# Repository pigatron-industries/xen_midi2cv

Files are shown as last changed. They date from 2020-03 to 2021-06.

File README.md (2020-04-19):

# MIDI - CV

MIDI to control voltage converter.

Uses [PJRC Teensy 4.0](https://www.pjrc.com/teensy-4-0/) and [MikroElektronika PIXI Click](https://www.mikroe.com/pixi-click) for IO.

## Hardware

Hardware functions are split into various PCBs.

* PGTNX05 Mainboard - Contains the Teensy 4 CPU, 2x MIDI Inputs and Outputs, 1x PIXI Click for 20 CV Outputs (12-bit).
* PGTNX06 IO Expander - Space for another 2x PIXI Click boards for up to 40 CV inputs or outputs.
* PGTNX07 Gate Output - 32x Gate/Trigger outputs.
* PGTNX08 Pitch Output - 8x 16-bit CV outputs for 1v/oct pitch control.

## Features

* 8 output channels each giving a Gate, Trigger, Pitch, Velocity and 2 Control Change outputs.
* Can be configured for a single MIDI channel to be mapped to multiple output channels for polyphonic operation.
* 8 separate percussion channel outputs with Trigger, and 2 Control Change outputs each, which can be mapped to individual notes on a single MIDI channel.

## Compiling

### Protobuf

Protobuf is used as a lightweight way of sending configuration data over midi sysex messages. The format of the message is specified in protobuf/ConfigMessage.proto.

If any changes are made to the format, the .c and .h files in the protobuf folder will need to be regenerated using the protobuf compiler.

This can be installed on Mac using the following commands:

`brew install protobuf`

`brew install nanopb-generator`

Then running the build.sh script will do the compilation.

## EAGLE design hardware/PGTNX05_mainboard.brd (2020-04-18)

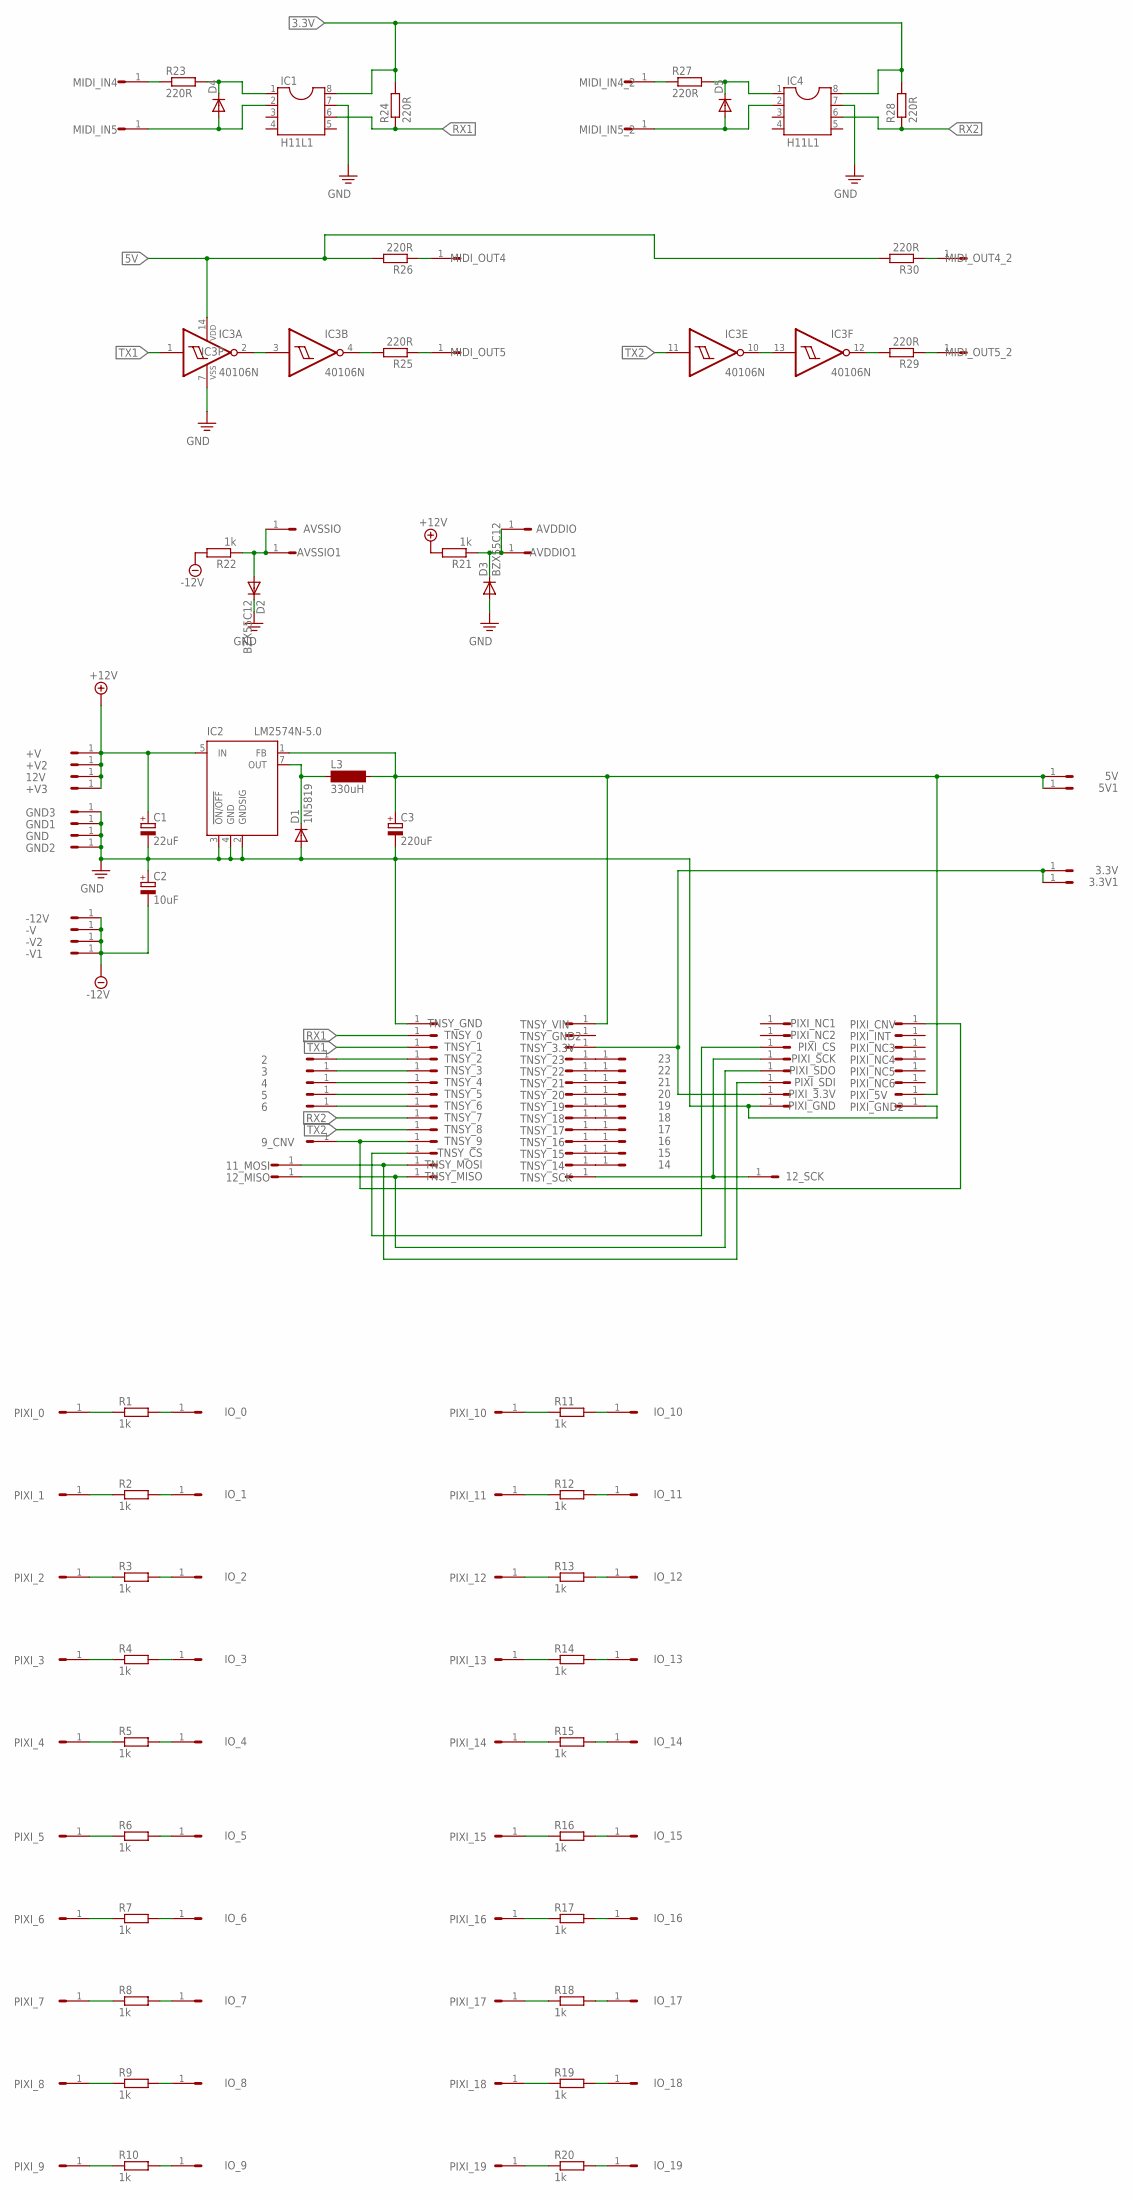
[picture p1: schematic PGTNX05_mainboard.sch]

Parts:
2, 3, 3.3V, 3.3V1, 4, 5, 5V, 5V1, 6, 9_CNV, 11_MOSI, 12V, 12_MISO, 12_SCK, 14, 15, 16, 17, 18, 19, 20, 21, 22, 23: HEADER/MALE/01
+V, +V2, +V3: HEADER/MALE/01
-12V: HEADER/MALE/01
-V, -V1, -V2: HEADER/MALE/01
AVDDIO, AVDDIO1: HEADER/MALE/01
AVSSIO, AVSSIO1: HEADER/MALE/01
C1: 22uF; E5-10,5
C2: 10uF; E2,5-6
C3: 220uF; E2,5-6
D1: 1N5819; DO35-7
D2, D3: BZX55C12; DO35-7
D4, D5: 1N4148DO35-7; DO35-7
GND, GND1, GND2, GND3: HEADER/MALE/01
IC1, IC4: H11L1; DIL08
IC2: LM2574N-5.0; DIL08
IC3: 40106N; DIL14
IO_0, IO_1, IO_2, IO_3, IO_4, IO_5, IO_6, IO_7, IO_8, IO_9, IO_10, IO_11, IO_12, IO_13, IO_14, IO_15, IO_16, IO_17, IO_18, IO_19: HEADER/MALE/01
L3: 330uH; BS11
MIDI_IN4, MIDI_IN4_2, MIDI_IN5, MIDI_IN5_2: HEADER/MALE/01
MIDI_OUT4, MIDI_OUT4_2, MIDI_OUT5, MIDI_OUT5_2: HEADER/MALE/01
PIXI_0, PIXI_1, PIXI_2, PIXI_3, PIXI_3.3V, PIXI_4, PIXI_5, PIXI_5V, PIXI_6, PIXI_7, PIXI_8, PIXI_9, PIXI_10, PIXI_11, PIXI_12, PIXI_13, PIXI_14, PIXI_15, PIXI_16, PIXI_17, PIXI_18, PIXI_19: HEADER/MALE/01
PIXI_CNV: HEADER/MALE/01
PIXI_CS: HEADER/MALE/01
PIXI_GND, PIXI_GND2: HEADER/MALE/01
PIXI_INT: HEADER/MALE/01
PIXI_NC1, PIXI_NC2, PIXI_NC3, PIXI_NC4, PIXI_NC5, PIXI_NC6: HEADER/MALE/01
PIXI_SCK: HEADER/MALE/01
PIXI_SDI: HEADER/MALE/01
PIXI_SDO: HEADER/MALE/01
R1, R2, R3, R4, R5, R6, R7, R8, R9, R10, R11, R12, R13, R14, R15, R16, R17, R18, R19, R20, R21, R22: 1k; RESISTOR/7.5
R23, R24, R25, R26, R27, R28, R29, R30: 220R; RESISTOR/7.5
TNSY_0, TNSY_1, TNSY_2, TNSY_3, TNSY_3.3V, TNSY_4, TNSY_5, TNSY_6, TNSY_7, TNSY_8, TNSY_9, TNSY_14, TNSY_15, TNSY_16, TNSY_17, TNSY_18, TNSY_19, TNSY_20, TNSY_21, TNSY_22, TNSY_23: HEADER/MALE/01
TNSY_CS: HEADER/MALE/01
TNSY_GND, TNSY_GND2: HEADER/MALE/01
TNSY_MISO: HEADER/MALE/01
TNSY_MOSI: HEADER/MALE/01
TNSY_SCK: HEADER/MALE/01
TNSY_VIN: HEADER/MALE/01

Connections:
3.3V: 3.3V.1, 3.3V1.1, IC1.8, IC4.8, PIXI_3.3V.1, R24.2, R28.2, TNSY_3.3V.1
5V: 5V.1, 5V1.1, C3.+, IC2.1 (FB), IC3.14 (VDD), L3.2, PIXI_5V.1, R26.2, R30.2, TNSY_VIN.1
+12V: 12V.1, +V.1, +V2.1, +V3.1, C1.+, IC2.5 (IN), R21.2
-12V: -12V.1, -V.1, -V1.1, -V2.1, C2.-, R22.2
GND: C1.-, C2.+, C3.-, D1.A, D2.C, D3.A, GND.1, GND1.1, GND2.1, GND3.1, IC1.7, IC2.2 (GNDSIG), IC2.3 (!ON/OFF), IC2.4 (GND), IC3.7 (VSS), IC4.7, PIXI_GND.1, PIXI_GND2.1, TNSY_GND.1
unnamed: 17.1, TNSY_17.1
unnamed: 16.1, TNSY_16.1
unnamed: D1.C, IC2.7 (OUT), L3.1
unnamed: 12_MISO.1, PIXI_SDO.1, TNSY_MISO.1
unnamed: PIXI_CS.1, TNSY_CS.1
unnamed: 18.1, TNSY_18.1
unnamed: 19.1, TNSY_19.1
unnamed: 20.1, TNSY_20.1
unnamed: 21.1, TNSY_21.1
unnamed: 22.1, TNSY_22.1
unnamed: 23.1, TNSY_23.1
unnamed: 15.1, TNSY_15.1
unnamed: 2.1, TNSY_2.1
unnamed: 3.1, TNSY_3.1
unnamed: 4.1, TNSY_4.1
unnamed: 5.1, TNSY_5.1
unnamed: PIXI_0.1, R1.1
unnamed: IO_0.1, R1.2
unnamed: PIXI_1.1, R2.1
unnamed: 6.1, TNSY_6.1
unnamed: IO_1.1, R2.2
unnamed: 9_CNV.1, PIXI_CNV.1, TNSY_9.1
unnamed: 11_MOSI.1, PIXI_SDI.1, TNSY_MOSI.1
unnamed: PIXI_2.1, R3.1
unnamed: 12_SCK.1, PIXI_SCK.1, TNSY_SCK.1
unnamed: 14.1, TNSY_14.1
unnamed: IO_2.1, R3.2
unnamed: PIXI_3.1, R4.1
unnamed: IO_3.1, R4.2
unnamed: PIXI_4.1, R5.1
unnamed: IO_4.1, R5.2
unnamed: PIXI_5.1, R6.1
unnamed: IO_5.1, R6.2
unnamed: PIXI_6.1, R7.1
unnamed: IO_6.1, R7.2
unnamed: PIXI_7.1, R8.1
unnamed: IO_7.1, R8.2
unnamed: PIXI_8.1, R9.1
unnamed: IO_8.1, R9.2
unnamed: PIXI_9.1, R10.1
unnamed: IO_9.1, R10.2
unnamed: PIXI_10.1, R11.1
unnamed: IO_10.1, R11.2
unnamed: PIXI_11.1, R12.1
unnamed: IO_11.1, R12.2
unnamed: PIXI_12.1, R13.1
unnamed: IO_12.1, R13.2
unnamed: PIXI_13.1, R14.1
unnamed: IO_13.1, R14.2
unnamed: PIXI_14.1, R15.1
unnamed: IO_14.1, R15.2
unnamed: PIXI_15.1, R16.1
unnamed: IO_15.1, R16.2
unnamed: PIXI_16.1, R17.1
unnamed: IO_16.1, R17.2
unnamed: PIXI_17.1, R18.1
unnamed: IO_17.1, R18.2
unnamed: PIXI_18.1, R19.1
unnamed: IO_18.1, R19.2
unnamed: AVDDIO.1, AVDDIO1.1, D3.C, R21.1
unnamed: AVSSIO.1, AVSSIO1.1, D2.A, R22.1
unnamed: PIXI_19.1, R20.1
unnamed: IO_19.1, R20.2
unnamed: MIDI_IN4.1, R23.1
unnamed: D4.C, IC1.1, R23.2
unnamed: D4.A, IC1.2, MIDI_IN5.1
unnamed: IC3.2 (O), IC3.3 (I)
unnamed: IC3.4 (O), R25.2
unnamed: MIDI_OUT5.1, R25.1
unnamed: MIDI_OUT4.1, R26.1
unnamed: MIDI_IN4_2.1, R27.1
unnamed: D5.C, IC4.1, R27.2
unnamed: D5.A, IC4.2, MIDI_IN5_2.1
unnamed: IC3.10 (O), IC3.13 (I)
unnamed: IC3.12 (O), R29.2
unnamed: MIDI_OUT5_2.1, R29.1
unnamed: MIDI_OUT4_2.1, R30.1
RX1: IC1.6, R24.1, TNSY_0.1
RX2: IC4.6, R28.1, TNSY_7.1
TX1: IC3.1 (I), TNSY_1.1
TX2: IC3.11 (I), TNSY_8.1

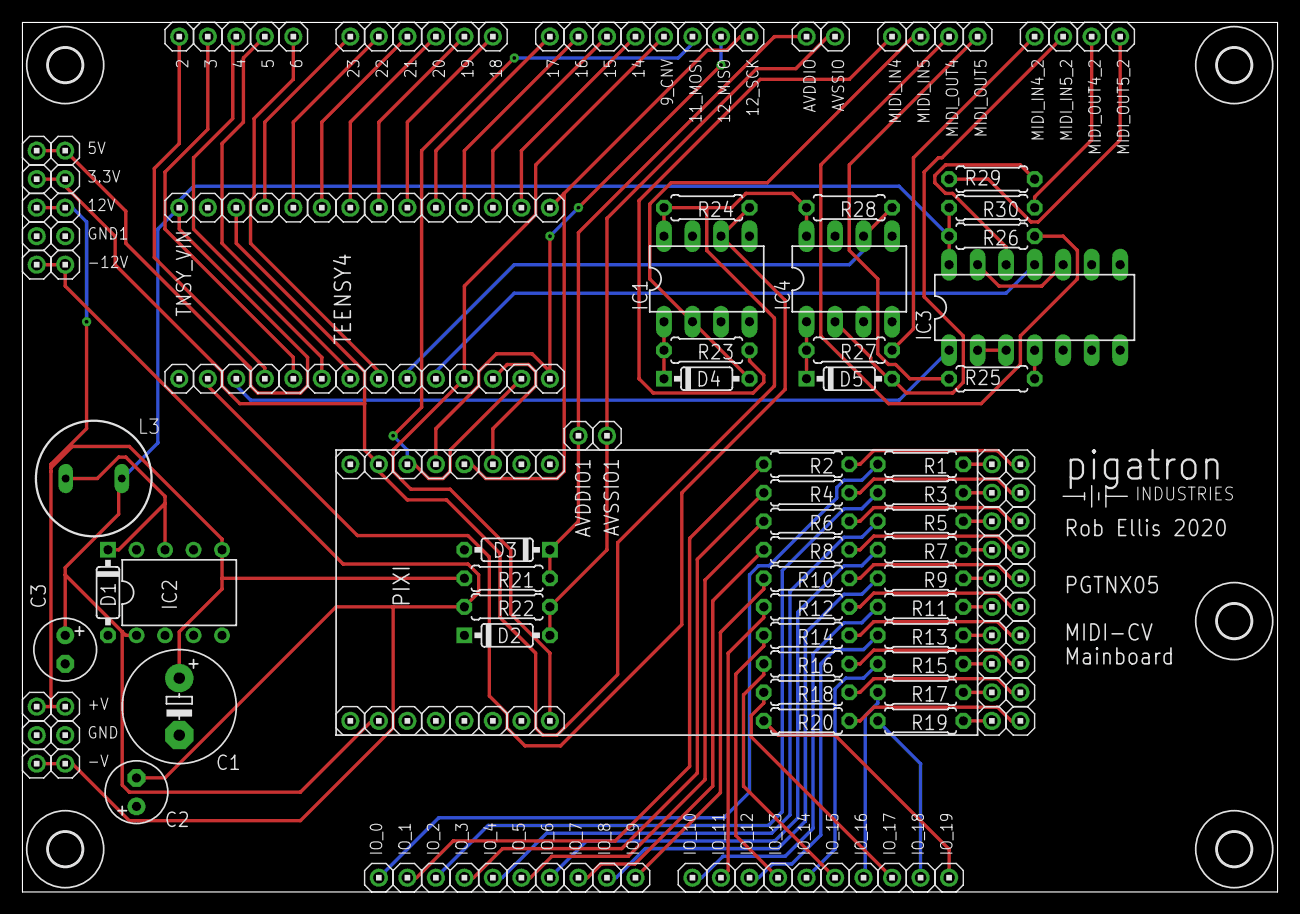
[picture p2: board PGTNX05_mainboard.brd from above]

Board: 2 copper layers, 111.8 x 77.5 mm, 180 parts (0 on the bottom side), 86 nets.

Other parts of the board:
U$1, U$2, U$3, U$4, U$7: STANDOFF/3.0
U$5: PIGATRON-LOGO

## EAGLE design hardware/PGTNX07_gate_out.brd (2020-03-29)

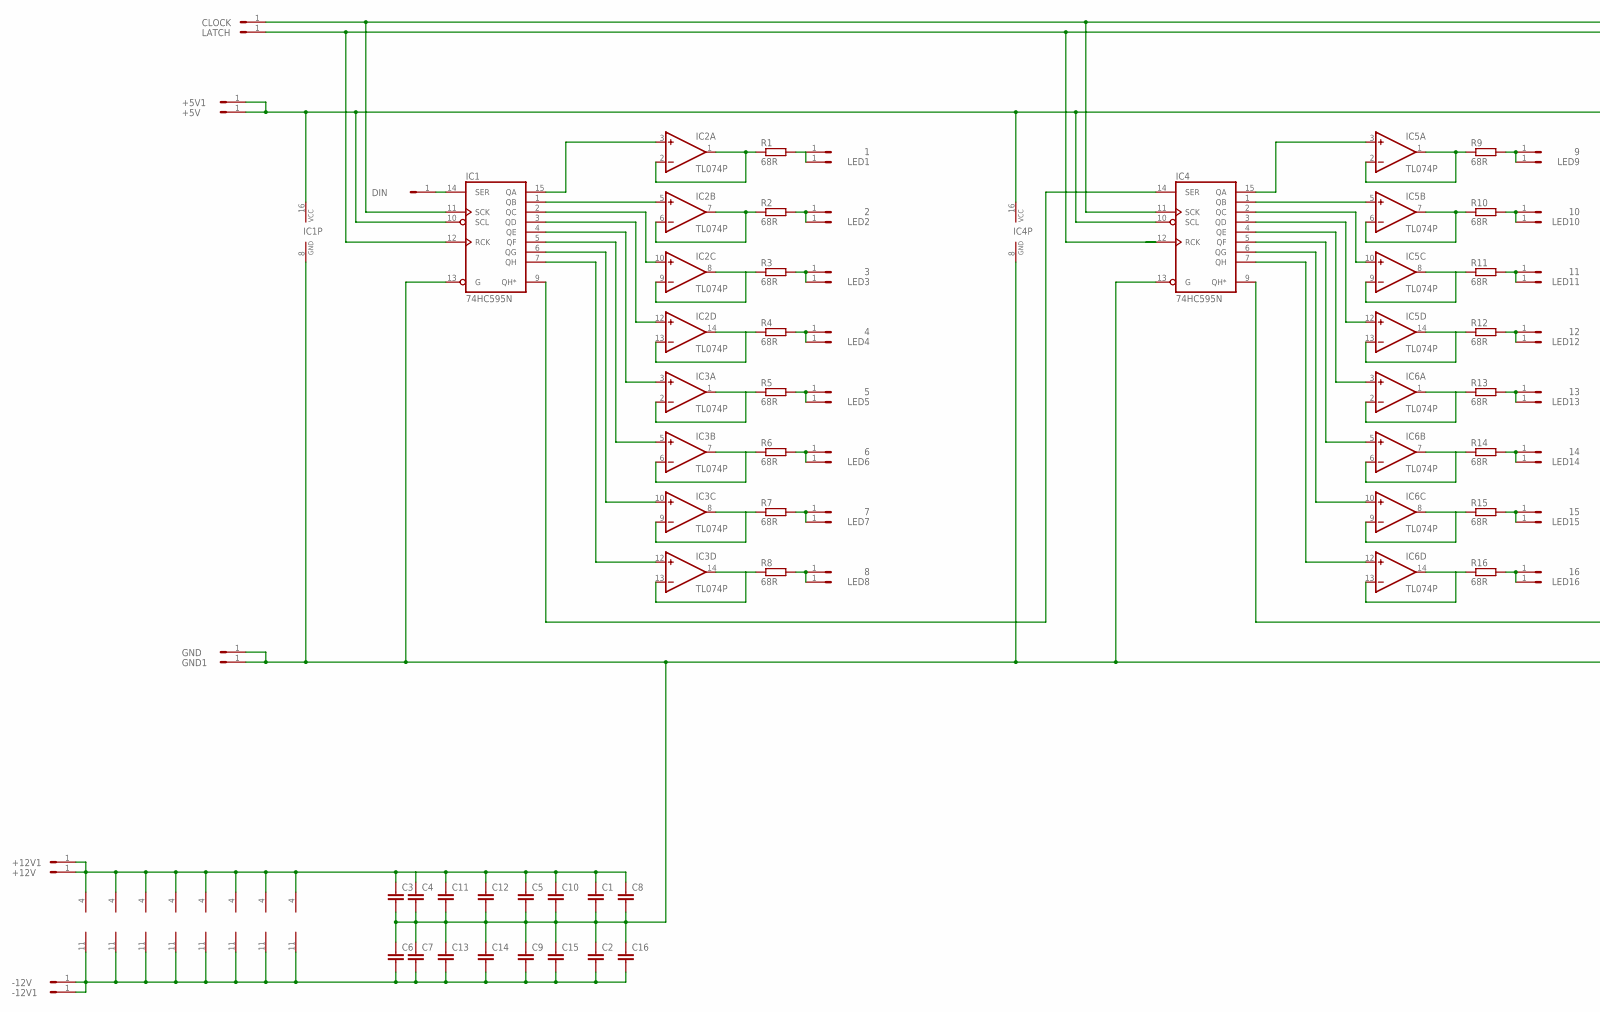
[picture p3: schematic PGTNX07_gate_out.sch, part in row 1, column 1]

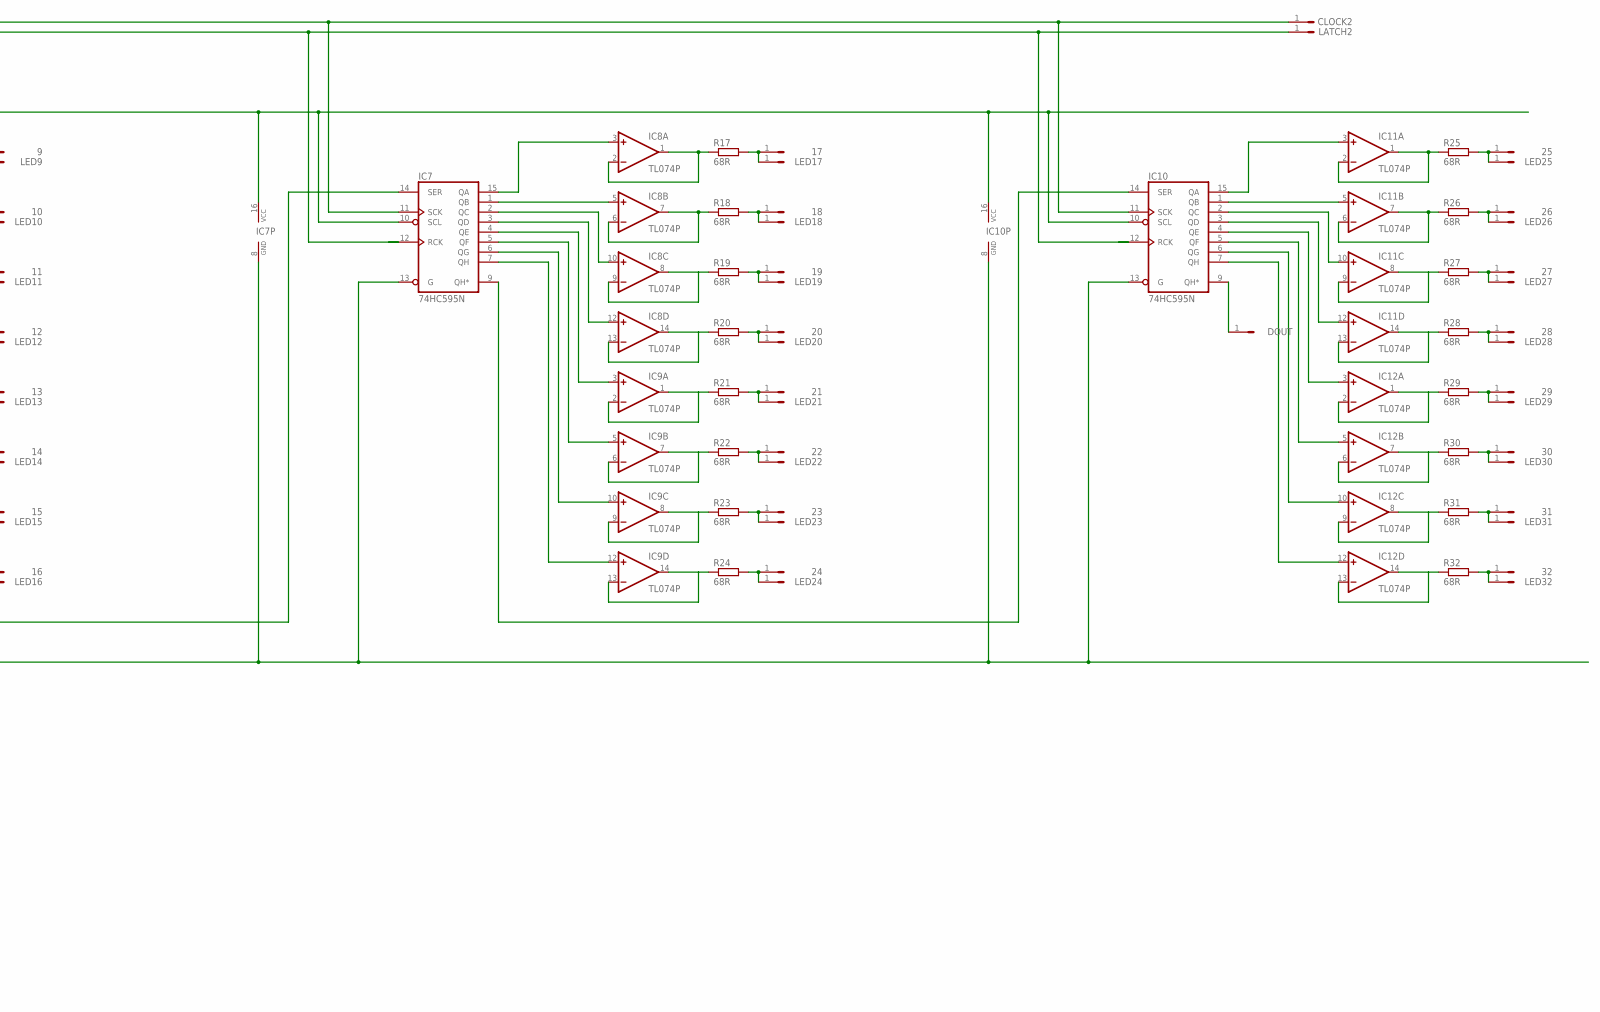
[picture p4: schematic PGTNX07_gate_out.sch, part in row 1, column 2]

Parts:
1, 2, 3, 4, 5, 6, 7, 8, 9, 10, 11, 12, 13, 14, 15, 16, 17, 18, 19, 20, 21, 22, 23, 24, 25, 26, 27, 28, 29, 30, 31, 32: HEADER/MALE/01
+5V, +5V1, +12V, +12V1: HEADER/MALE/01
-12V, -12V1: HEADER/MALE/01
C1, C2, C3, C4, C5, C6, C7, C8, C9, C10, C11, C12, C13, C14, C15, C16: CAPACITORCERAMICDISC/5; CERAMICDISC/5
CLOCK, CLOCK2: HEADER/MALE/01
DIN: HEADER/MALE/01
DOUT: HEADER/MALE/01
GND, GND1: HEADER/MALE/01
IC1, IC4, IC7, IC10: 74HC595N; DIL16
IC2, IC3, IC5, IC6, IC8, IC9, IC11, IC12: TL074P; DIL14
LATCH, LATCH2: HEADER/MALE/01
LED1, LED2, LED3, LED4, LED5, LED6, LED7, LED8, LED9, LED10, LED11, LED12, LED13, LED14, LED15, LED16, LED17, LED18, LED19, LED20, LED21, LED22, LED23, LED24, LED25, LED26, LED27, LED28, LED29, LED30, LED31, LED32: HEADER/MALE/01
R1, R2, R3, R4, R5, R6, R7, R8, R9, R10, R11, R12, R13, R14, R15, R16, R17, R18, R19, R20, R21, R22, R23, R24, R25, R26, R27, R28, R29, R30, R31, R32: 68R; RESISTOR/7.5

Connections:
+5V: +5V.1, +5V1.1, IC1.10 (SCL), IC1.16 (VCC), IC4.10 (SCL), IC4.16 (VCC), IC7.10 (SCL), IC7.16 (VCC), IC10.10 (SCL), IC10.16 (VCC)
GND: C1.2, C2.1, C3.2, C4.2, C5.2, C6.1, C7.1, C8.2, C9.1, C10.2, C11.2, C12.2, C13.1, C14.1, C15.1, C16.1, GND.1, GND1.1, IC1.8 (GND), IC1.13 (G), IC4.8 (GND), IC4.13 (G), IC7.8 (GND), IC7.13 (G), IC10.8 (GND), IC10.13 (G)
unnamed: IC1.15 (QA), IC2.3 (+IN)
unnamed: IC1.1 (QB), IC2.5 (+IN)
unnamed: DIN.1, IC1.14 (SER)
unnamed: IC1.2 (QC), IC2.10 (+IN)
unnamed: IC1.3 (QD), IC2.12 (+IN)
unnamed: IC1.4 (QE), IC3.3 (+IN)
unnamed: IC1.5 (QF), IC3.5 (+IN)
unnamed: IC1.6 (QG), IC3.10 (+IN)
unnamed: IC1.7 (QH), IC3.12 (+IN)
unnamed: IC1.9 (QH*), IC4.14 (SER)
unnamed: IC2.1 (OUT), IC2.2 (-IN), R1.1
unnamed: 1.1, LED1.1, R1.2
unnamed: IC2.6 (-IN), IC2.7 (OUT), R2.1
unnamed: 2.1, LED2.1, R2.2
unnamed: +12V.1, +12V1.1, C1.1, C3.1, C4.1, C5.1, C8.1, C10.1, C11.1, C12.1, IC2.4 (V+), IC3.4 (V+), IC5.4 (V+), IC6.4 (V+), IC8.4 (V+), IC9.4 (V+), IC11.4 (V+), IC12.4 (V+)
unnamed: -12V.1, -12V1.1, C2.2, C6.2, C7.2, C9.2, C13.2, C14.2, C15.2, C16.2, IC2.11 (V-), IC3.11 (V-), IC5.11 (V-), IC6.11 (V-), IC8.11 (V-), IC9.11 (V-), IC11.11 (V-), IC12.11 (V-)
unnamed: CLOCK.1, CLOCK2.1, IC1.11 (SCK), IC4.11 (SCK), IC7.11 (SCK), IC10.11 (SCK)
unnamed: IC2.8 (OUT), IC2.9 (-IN), R3.1
unnamed: IC2.13 (-IN), IC2.14 (OUT), R4.1
unnamed: IC3.1 (OUT), IC3.2 (-IN), R5.1
unnamed: IC3.6 (-IN), IC3.7 (OUT), R6.1
unnamed: IC3.8 (OUT), IC3.9 (-IN), R7.1
unnamed: IC3.13 (-IN), IC3.14 (OUT), R8.1
unnamed: 3.1, LED3.1, R3.2
unnamed: 4.1, LED4.1, R4.2
unnamed: 5.1, LED5.1, R5.2
unnamed: 6.1, LED6.1, R6.2
unnamed: 7.1, LED7.1, R7.2
unnamed: 8.1, LED8.1, R8.2
unnamed: IC1.12 (RCK), IC4.12 (RCK), IC7.12 (RCK), IC10.12 (RCK), LATCH.1, LATCH2.1
unnamed: IC4.9 (QH*), IC7.14 (SER)
unnamed: IC4.2 (QC), IC5.10 (+IN)
unnamed: IC4.3 (QD), IC5.12 (+IN)
unnamed: IC4.4 (QE), IC6.3 (+IN)
unnamed: IC4.5 (QF), IC6.5 (+IN)
unnamed: IC4.6 (QG), IC6.10 (+IN)
unnamed: IC4.15 (QA), IC5.3 (+IN)
unnamed: IC4.1 (QB), IC5.5 (+IN)
unnamed: IC4.7 (QH), IC6.12 (+IN)
unnamed: IC5.1 (OUT), IC5.2 (-IN), R9.1
unnamed: 9.1, LED9.1, R9.2
unnamed: IC5.6 (-IN), IC5.7 (OUT), R10.1
unnamed: 10.1, LED10.1, R10.2
unnamed: IC7.9 (QH*), IC10.14 (SER)
unnamed: IC7.2 (QC), IC8.10 (+IN)
unnamed: IC5.8 (OUT), IC5.9 (-IN), R11.1
unnamed: IC5.13 (-IN), IC5.14 (OUT), R12.1
unnamed: IC6.1 (OUT), IC6.2 (-IN), R13.1
unnamed: IC6.6 (-IN), IC6.7 (OUT), R14.1
unnamed: IC6.8 (OUT), IC6.9 (-IN), R15.1
unnamed: IC6.13 (-IN), IC6.14 (OUT), R16.1
unnamed: 11.1, LED11.1, R11.2
unnamed: 12.1, LED12.1, R12.2
unnamed: 13.1, LED13.1, R13.2
unnamed: 14.1, LED14.1, R14.2
unnamed: 15.1, LED15.1, R15.2
unnamed: 16.1, LED16.1, R16.2
unnamed: IC7.3 (QD), IC8.12 (+IN)
unnamed: IC7.4 (QE), IC9.3 (+IN)
unnamed: IC7.5 (QF), IC9.5 (+IN)
unnamed: IC7.6 (QG), IC9.10 (+IN)
unnamed: IC7.15 (QA), IC8.3 (+IN)
unnamed: IC7.1 (QB), IC8.5 (+IN)
unnamed: IC7.7 (QH), IC9.12 (+IN)
unnamed: IC8.1 (OUT), IC8.2 (-IN), R17.1
unnamed: 17.1, LED17.1, R17.2
unnamed: IC8.6 (-IN), IC8.7 (OUT), R18.1
unnamed: 18.1, LED18.1, R18.2
unnamed: IC8.8 (OUT), IC8.9 (-IN), R19.1
unnamed: IC8.13 (-IN), IC8.14 (OUT), R20.1
unnamed: IC9.1 (OUT), IC9.2 (-IN), R21.1
unnamed: IC9.6 (-IN), IC9.7 (OUT), R22.1
unnamed: IC9.8 (OUT), IC9.9 (-IN), R23.1
unnamed: IC9.13 (-IN), IC9.14 (OUT), R24.1
unnamed: 19.1, LED19.1, R19.2
unnamed: 20.1, LED20.1, R20.2
unnamed: 21.1, LED21.1, R21.2
unnamed: 22.1, LED22.1, R22.2
unnamed: 23.1, LED23.1, R23.2
unnamed: 24.1, LED24.1, R24.2
unnamed: DOUT.1, IC10.9 (QH*)
unnamed: IC10.2 (QC), IC11.10 (+IN)
unnamed: IC10.3 (QD), IC11.12 (+IN)
unnamed: IC10.4 (QE), IC12.3 (+IN)
unnamed: IC10.5 (QF), IC12.5 (+IN)
unnamed: IC10.6 (QG), IC12.10 (+IN)
unnamed: IC10.15 (QA), IC11.3 (+IN)
unnamed: IC10.1 (QB), IC11.5 (+IN)
unnamed: IC10.7 (QH), IC12.12 (+IN)
unnamed: IC11.1 (OUT), IC11.2 (-IN), R25.1
unnamed: 25.1, LED25.1, R25.2
unnamed: IC11.6 (-IN), IC11.7 (OUT), R26.1
unnamed: 26.1, LED26.1, R26.2
unnamed: IC11.8 (OUT), IC11.9 (-IN), R27.1
unnamed: IC11.13 (-IN), IC11.14 (OUT), R28.1
unnamed: IC12.1 (OUT), IC12.2 (-IN), R29.1
unnamed: IC12.6 (-IN), IC12.7 (OUT), R30.1
unnamed: IC12.8 (OUT), IC12.9 (-IN), R31.1
unnamed: IC12.13 (-IN), IC12.14 (OUT), R32.1
unnamed: 27.1, LED27.1, R27.2
unnamed: 28.1, LED28.1, R28.2
unnamed: 29.1, LED29.1, R29.2
unnamed: 30.1, LED30.1, R30.2
unnamed: 31.1, LED31.1, R31.2
unnamed: 32.1, LED32.1, R32.2

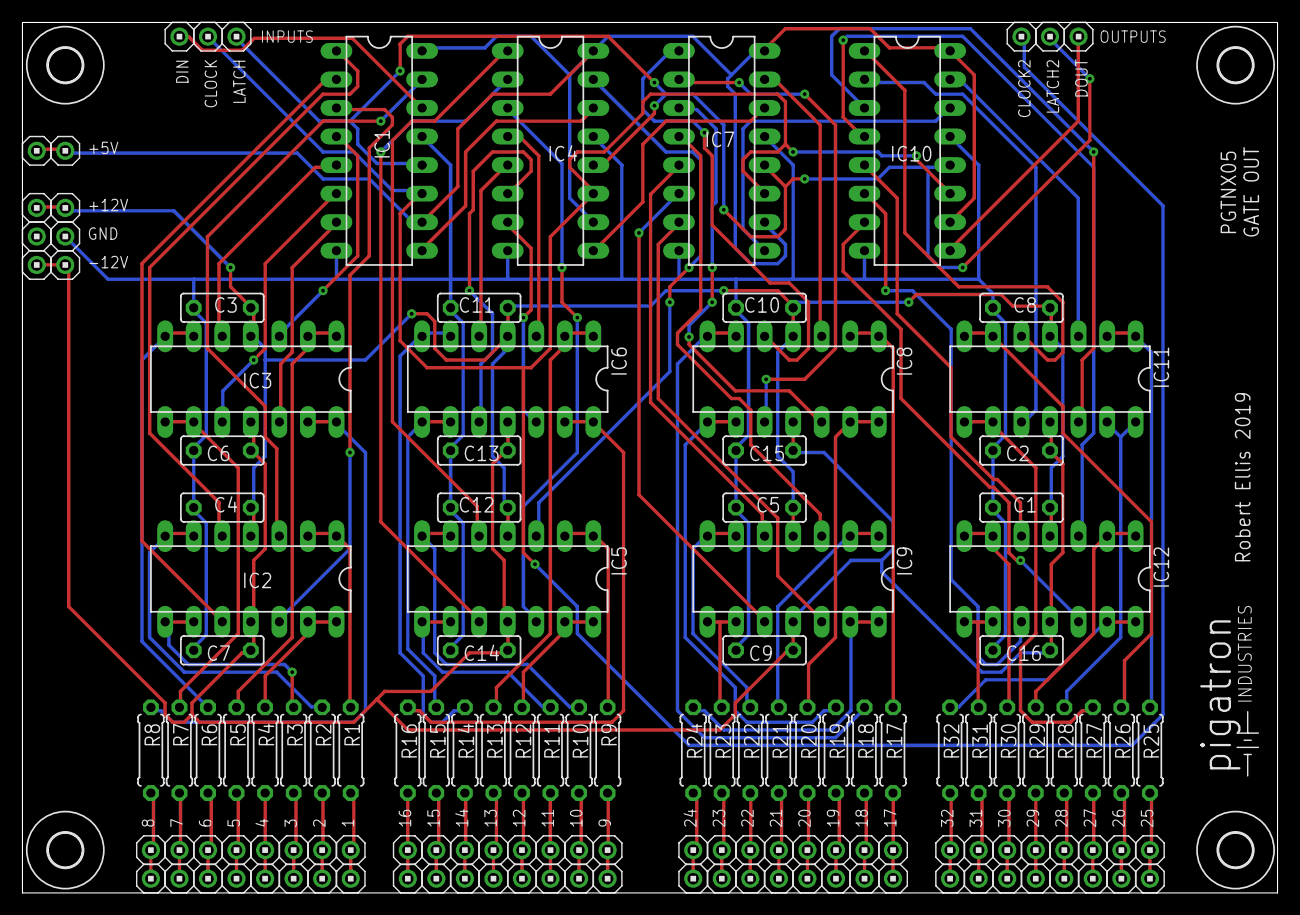
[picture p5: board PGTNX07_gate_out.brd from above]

Board: 2 copper layers, 111.7 x 77.5 mm, 143 parts (0 on the bottom side), 107 nets.

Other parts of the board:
U$1, U$2, U$3, U$4: STANDOFF/3.0
U$5: PIGATRON-LOGO

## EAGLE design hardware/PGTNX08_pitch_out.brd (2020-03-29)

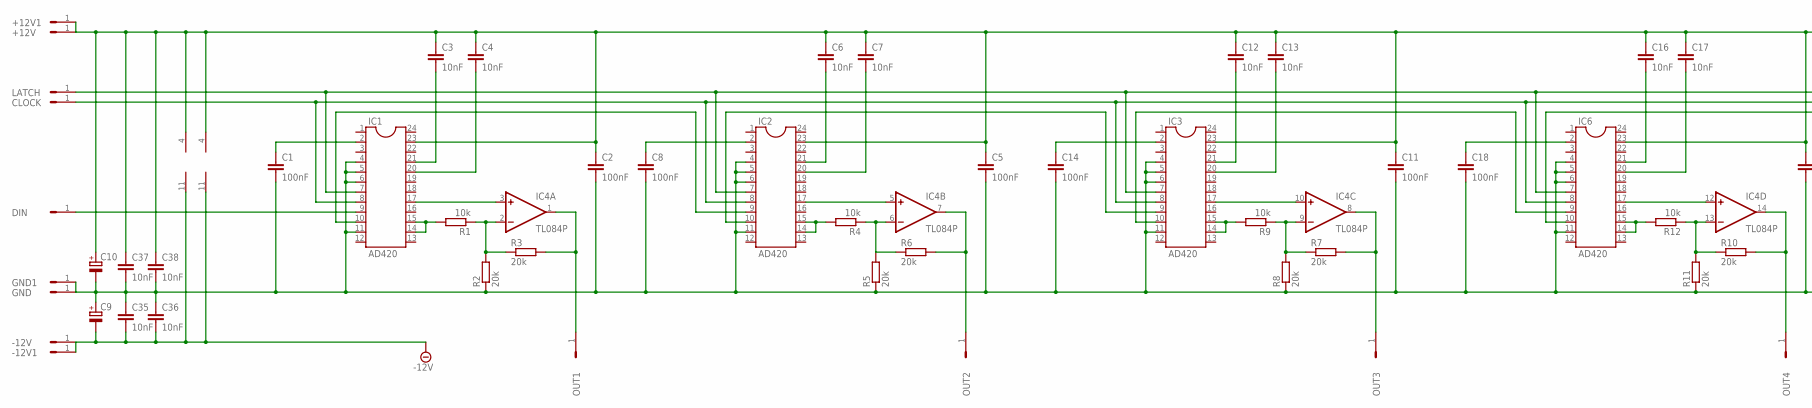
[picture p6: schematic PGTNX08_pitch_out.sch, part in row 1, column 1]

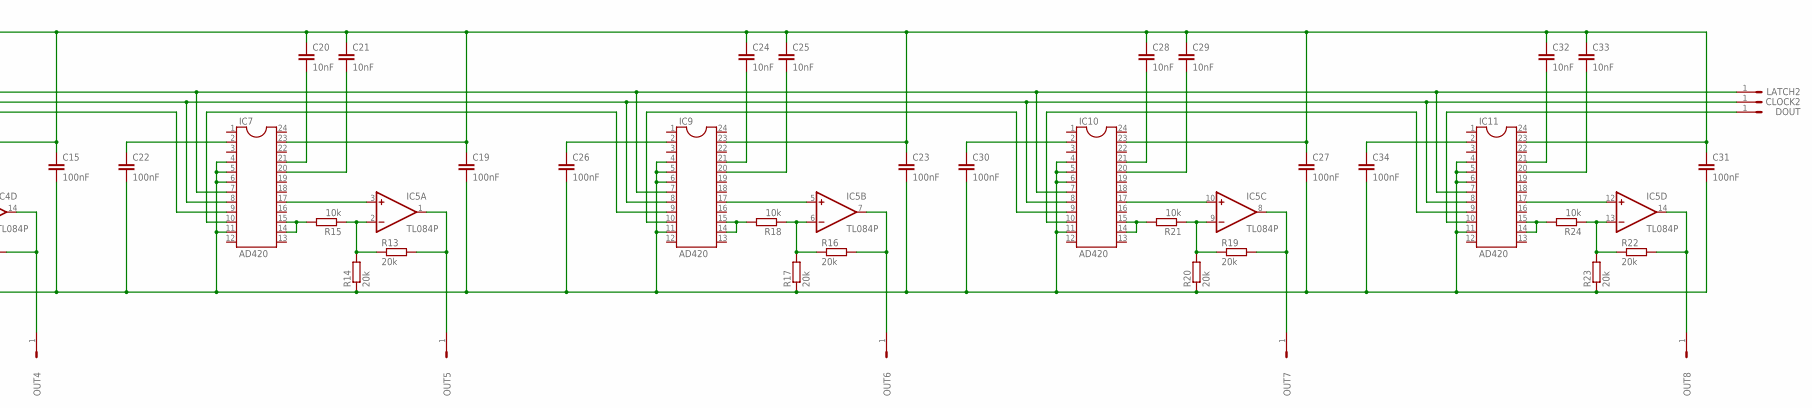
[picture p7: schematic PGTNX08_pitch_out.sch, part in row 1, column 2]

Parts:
+12V, +12V1: HEADER/MALE/01
-12V, -12V1: HEADER/MALE/01
C1, C2, C5, C8, C11, C14, C15, C18, C19, C22, C23, C26, C27, C30, C31, C34: 100nF; CERAMICDISC/5
C3, C4, C6, C7, C12, C13, C16, C17, C20, C21, C24, C25, C28, C29, C32, C33, C35, C36, C37, C38: 10nF; CERAMICDISC/5
C9, C10: CAPACITOR/POLARIZEDE2.5-6; E2,5-6
CLOCK, CLOCK2: HEADER/MALE/01
DIN: HEADER/MALE/01
DOUT: HEADER/MALE/01
GND, GND1: HEADER/MALE/01
IC1, IC2, IC3, IC6, IC7, IC9, IC10, IC11: AD420; DIL24-3
IC4, IC5: TL084P; DIL14
LATCH, LATCH2: HEADER/MALE/01
OUT1, OUT2, OUT3, OUT4, OUT5, OUT6, OUT7, OUT8: HEADER/MALE/01
R1, R4: 10k; 0204/7
R2, R5: 20k; 0204/7
R3, R6, R7, R8, R10, R11, R13, R14, R16, R17, R19, R20, R22, R23: 20k; RESISTOR/7.5
R9, R12, R15, R18, R21, R24: 10k; RESISTOR/7.5

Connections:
+12V: +12V.1, +12V1.1, C2.1, C3.1, C4.1, C5.1, C6.1, C7.1, C10.+, C11.1, C12.1, C13.1, C15.1, C16.1, C17.1, C19.1, C20.1, C21.1, C23.1, C24.1, C25.1, C27.1, C28.1, C29.1, C31.1, C32.1, C33.1, C37.1, C38.1, IC1.23, IC2.23, IC3.23, IC4.4 (V+), IC5.4 (V+), IC6.23, IC7.23, IC9.23, IC10.23, IC11.23
-12V: -12V.1, -12V1.1, C9.-, C35.2, C36.2, IC4.11 (V-), IC5.11 (V-)
GND: C1.2, C2.2, C5.2, C8.2, C9.+, C10.-, C11.2, C14.2, C15.2, C18.2, C19.2, C22.2, C23.2, C26.2, C27.2, C30.2, C31.2, C34.2, C35.1, C36.1, C37.2, C38.2, GND.1, GND1.1, IC1.4, IC1.5, IC1.6, IC1.11, IC2.4, IC2.5, IC2.6, IC2.11, IC3.4, IC3.5, IC3.6, IC3.11, IC6.4, IC6.5, IC6.6, IC6.11, IC7.4, IC7.5, IC7.6, IC7.11, IC9.4, IC9.5, IC9.6, IC9.11, IC10.4, IC10.5, IC10.6, IC10.11, IC11.4, IC11.5, IC11.6, IC11.11, R2.1, R5.1, R8.1, R11.1, R14.1, R17.1, R20.1, R23.1
unnamed: IC3.10, IC6.9
unnamed: IC6.10, IC7.9
unnamed: DIN.1, IC1.9
unnamed: IC2.14, IC2.15, R4.2
unnamed: IC2.10, IC3.9
unnamed: IC4.2 (-IN), R1.1, R2.2, R3.1
unnamed: IC9.10, IC10.9
unnamed: C1.1, IC1.2
unnamed: C3.2, IC1.21
unnamed: C4.2, IC1.20
unnamed: IC1.17, IC4.3 (+IN)
unnamed: IC1.14, IC1.15, R1.2
unnamed: IC4.1 (OUT), OUT1.1, R3.2
unnamed: IC7.10, IC9.9
unnamed: IC1.10, IC2.9
unnamed: IC2.17, IC4.5 (+IN)
unnamed: IC4.7 (OUT), OUT2.1, R6.2
unnamed: IC3.14, IC3.15, R9.2
unnamed: C8.1, IC2.2
unnamed: C6.2, IC2.21
unnamed: C7.2, IC2.20
unnamed: IC4.6 (-IN), R4.1, R5.2, R6.1
unnamed: IC3.17, IC4.10 (+IN)
unnamed: IC4.8 (OUT), OUT3.1, R7.2
unnamed: C14.1, IC3.2
unnamed: C12.2, IC3.21
unnamed: C13.2, IC3.20
unnamed: IC10.10, IC11.9
unnamed: IC4.9 (-IN), R7.1, R8.2, R9.1
unnamed: IC6.14, IC6.15, R12.2
unnamed: IC4.12 (+IN), IC6.17
unnamed: IC4.14 (OUT), OUT4.1, R10.2
unnamed: C18.1, IC6.2
unnamed: C16.2, IC6.21
unnamed: C17.2, IC6.20
unnamed: CLOCK.1, CLOCK2.1, IC1.8, IC2.8, IC3.8, IC6.8, IC7.8, IC9.8, IC10.8, IC11.8
unnamed: IC4.13 (-IN), R10.1, R11.2, R12.1
unnamed: IC7.14, IC7.15, R15.2
unnamed: IC5.3 (+IN), IC7.17
unnamed: IC5.1 (OUT), OUT5.1, R13.2
unnamed: C22.1, IC7.2
unnamed: C20.2, IC7.21
unnamed: C21.2, IC7.20
unnamed: IC5.2 (-IN), R13.1, R14.2, R15.1
unnamed: IC9.14, IC9.15, R18.2
unnamed: IC5.5 (+IN), IC9.17
unnamed: IC5.7 (OUT), OUT6.1, R16.2
unnamed: C26.1, IC9.2
unnamed: C24.2, IC9.21
unnamed: C25.2, IC9.20
unnamed: DOUT.1, IC11.10
unnamed: IC5.6 (-IN), R16.1, R17.2, R18.1
unnamed: IC10.14, IC10.15, R21.2
unnamed: IC5.10 (+IN), IC10.17
unnamed: IC5.8 (OUT), OUT7.1, R19.2
unnamed: C30.1, IC10.2
unnamed: C28.2, IC10.21
unnamed: C29.2, IC10.20
unnamed: IC5.9 (-IN), R19.1, R20.2, R21.1
unnamed: IC11.14, IC11.15, R24.2
unnamed: IC5.12 (+IN), IC11.17
unnamed: IC5.14 (OUT), OUT8.1, R22.2
unnamed: C34.1, IC11.2
unnamed: C32.2, IC11.21
unnamed: C33.2, IC11.20
unnamed: IC1.7, IC2.7, IC3.7, IC6.7, IC7.7, IC9.7, IC10.7, IC11.7, LATCH.1, LATCH2.1
unnamed: IC5.13 (-IN), R22.1, R23.2, R24.1

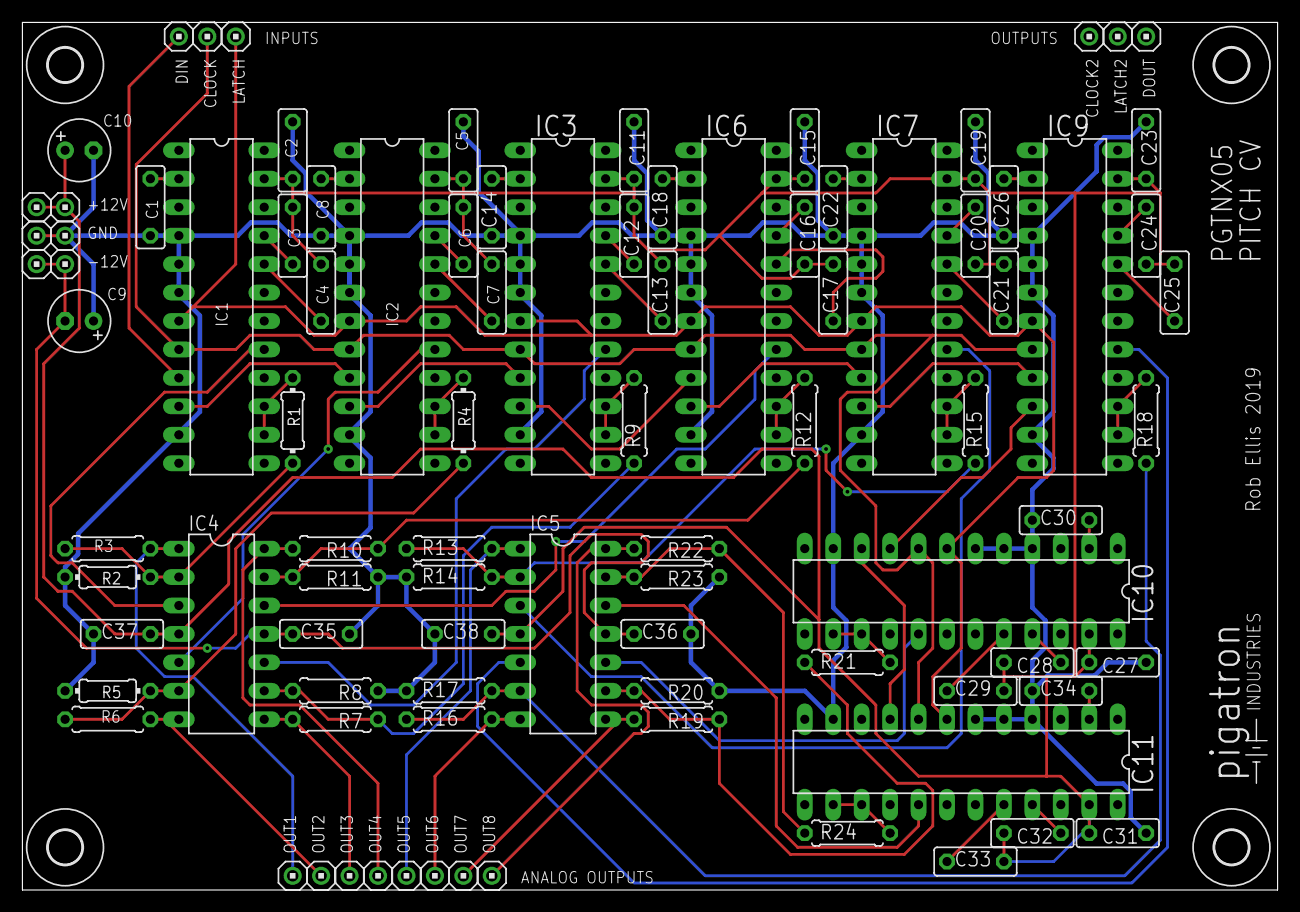
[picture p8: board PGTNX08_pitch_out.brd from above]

Board: 2 copper layers, 112.1 x 77.5 mm, 97 parts (0 on the bottom side), 70 nets.

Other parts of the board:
U$1, U$2, U$3, U$4: 3,0
U$5: PIGATRON-LOGO

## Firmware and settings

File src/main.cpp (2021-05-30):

#include <Arduino.h>

#include "hwconfig.h"

#include "config/Configuration.h"
#include "drivers/PitchCvOutput.h"
#include "drivers/CvOutput.h"
#include "drivers/CvOutputService.h"
#include "programs/OutputUpdateTask.h"
#include "programs/midi/MidiEventProcessor.h"
#include "programs/midi/MidiInputTask.h"
#include "programs/midi/MidiOutputService.h"
#include "programs/midi/UsbMidiInputTask.h"


// hardware
GateOutput gateOutput = GateOutput(GATE_DATA_PIN, GATE_LATCH_PIN, GATE_CLOCK_PIN, CV_CHANNELS*GATE_BANKS);
PitchCvOutput pitchCvOutput = PitchCvOutput(PITCHCV_DATA_PIN, PITCHCV_LATCH_PIN, PITCHCV_CLOCK_PIN, CV_CHANNELS);
uint8_t cvSelectPins[CV_DEVICES] = CV_SELECT_PINS;
CvOutput cvOutput = CvOutput(&SPI, CV_CNVT_PIN, cvSelectPins, CV_DEVICES);

Configuration config = Configuration();

CvOutputService cvOutputService = CvOutputService(config, gateOutput, pitchCvOutput, cvOutput);

MidiToPitchConverter midiToPitchConverter = MidiToPitchConverter(config);
MidiEventProcessor midiEventProcessor = MidiEventProcessor(config, cvOutputService, midiToPitchConverter);
MidiOutputService midiOutputService = MidiOutputService(Serial2, Serial3);
MidiInputTask midiInputTask1 = MidiInputTask(Serial1, midiEventProcessor, midiOutputService);
MidiInputTask midiInputTask2 = MidiInputTask(Serial2, midiEventProcessor, midiOutputService);
MidiInputTask midiInputTask3 = MidiInputTask(Serial3, midiEventProcessor, midiOutputService);
UsbMidiInputTask usbMidiInputTask = UsbMidiInputTask(midiEventProcessor, midiOutputService);
OutputUpdateTask outputUpdateTask = OutputUpdateTask(cvOutputService);

void setup() {
    Serial.begin(SERIAL_BAUD);
    Serial.println();
    Serial.println("======================================");
    Serial.println("*     Pigatron Industries Midi2Cv    *");
    Serial.println("======================================");
    Serial.println();
    config.printConfig();

    midiInputTask1.init();
    midiInputTask2.init();
    midiInputTask3.init();
    usbMidiInputTask.init();
    outputUpdateTask.init();
}

void loop() {
    midiInputTask1.execute();
    midiInputTask2.execute();
    midiInputTask3.execute();
    usbMidiInputTask.execute();
    outputUpdateTask.execute();
}

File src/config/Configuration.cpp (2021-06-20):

#include "Configuration.h"

#include <Arduino.h>

#include "../lib/nanopb/pb_decode.h"
#include "../hwconfig.h"



Configuration::Configuration() {
    resetDefault();
}


xen_ChannelMapping* Configuration::getCvChannelMapping(uint8_t midiChannel) {
    for(int i = 0; i < config.channelConfig.channelMapping_count; i++) {
        if(config.channelConfig.channelMapping[i].midiChannel == midiChannel) {
            return &config.channelConfig.channelMapping[i];
        }
    }
    return NULL;
}


xen_ControllerMapping* Configuration::getCvControllerMapping(int8_t midiChannel, int8_t midiController) {
    for(int i = 0; i < config.controllerConfig.controllerMapping_count; i++) {
        if(config.controllerConfig.controllerMapping[i].midiChannel == midiChannel &&
          config.controllerConfig.controllerMapping[i].midiController == midiController) {
              return &config.controllerConfig.controllerMapping[i];
        }
    }
    return NULL;
}


xen_PercussionMapping* Configuration::getPercussionMapping(int8_t midiNote) {
    for(int i = 0; i < config.percussionChannelConfig.percussionMapping_count; i++) {
        if(config.percussionChannelConfig.percussionMapping[i].midiNote == midiNote) {
              return &config.percussionChannelConfig.percussionMapping[i];
        }
    }
    return NULL;
}


xen_PercussionChannelConfig* Configuration::getPercussionChannelConfig() {
    return &config.percussionChannelConfig;
}


float Configuration::getNoteCents(int8_t noteNum) {
    if(noteNum == 0) {
        return 0;
    } else {
        return config.scale.cents[noteNum-1];
    }
}


float Configuration::getOctaveCents() {
    return config.scale.cents[config.scale.cents_count-1];
}


int8_t Configuration::getNoteCount() {
    return config.scale.cents_count;
}


void Configuration::configUpdateMessage(uint8_t* encodedMessage, size_t size) {
    xen_ConfigWrapper configMessage = xen_ConfigWrapper_init_zero;
    pb_istream_t stream = pb_istream_from_buffer(encodedMessage, size);
    bool status = pb_decode(&stream, xen_ConfigWrapper_fields, &configMessage);
    if (!status) {
        Serial.println("Decoding config failed");
        Serial.println(PB_GET_ERROR(&stream));
        return;
    }

    if(configMessage.has_channelConfig) {
        config.channelConfig = configMessage.channelConfig;
    }

    if(configMessage.has_controllerConfig) {
        config.controllerConfig = configMessage.controllerConfig;
    }

    if(configMessage.has_scale) {
        config.scale = configMessage.scale;
    }

    if(configMessage.has_triggerTime) {
        config.triggerTime = configMessage.triggerTime;
    }

    printConfig();
}


void Configuration::printConfig() {
    Serial.println("System configured:");
    Serial.println();
    Serial.println("     Channel Mappings");
    for(int i = 0; i < config.channelConfig.channelMapping_count; i++) {
        Serial.print("          MIDI: ");
        Serial.print(config.channelConfig.channelMapping[i].midiChannel);
        Serial.print(" -> CV: ");
        Serial.print(config.channelConfig.channelMapping[i].cvChannelFrom);
        Serial.print(" - ");
        Serial.print(config.channelConfig.channelMapping[i].cvChannelTo);
        Serial.println();
    }

    Serial.println();
    Serial.println("     Scale");
    Serial.print("          Notes/octave: ");
    Serial.println(getNoteCount());
    Serial.print("          Octave size: ");
    Serial.println(getOctaveCents());
    for(int i = 0; i < config.scale.cents_count; i++) {
        Serial.print("          ");
        Serial.print(i);
        Serial.print(" -> ");
        Serial.print(getNoteCents(i));
        Serial.println();
    }

    Serial.println();
}

unsigned long Configuration::getTriggerTime() {
    return config.triggerTime;
}


/******************************************************************************
 *                          Default Configuration                             *
 ******************************************************************************/

void Configuration::resetDefault() {
    config = xen_ConfigWrapper_init_zero;
    defaultChannelConfig();
    defaultPercussionConfig();
    defaultControllerConfig();
    defaultScale();
    config.triggerTime = 5000;
}
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

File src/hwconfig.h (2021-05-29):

// Hardware setup
#define GATE_LATCH_PIN 18
#define GATE_CLOCK_PIN 19
#define GATE_DATA_PIN 20

#define PITCHCV_LATCH_PIN 21
#define PITCHCV_CLOCK_PIN 22
#define PITCHCV_DATA_PIN 23

#define CV_MOSI_PIN 11
#define CV_MISO_PIN 12
#define CV_SCLK_PIN 13
#define CV_SELECT_PINS {10, 16}
#define CV_CNVT_PIN 9

#define CV_CHANNELS 8 // number of output channels
#define GATE_BANKS 4  // number of banks of gates
#define CV_DEVICES 2
#define CV_CONTROLS 40
#define TRIGGER_CONTROLS 16

#define MIDI_BAUD 31250
#define SERIAL_BAUD 115200

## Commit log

2019-09-29 A lot of code to just blink a blue led
2019-10-05 Added 3 status leds + midi input task
2019-10-05 Fixed compile error and added serial output for debugging
    [MidiInputTask.cpp, main.cpp]
2019-10-11 Pitch CV Dac driver
2019-10-16 Add configuration object
    [Configuration.h]
2019-10-17 Add midi channel mappings to configuration object
    [Configuration.h]
2019-10-19 Fixed issues after hardware testing. Handle midi messages longer than 3 bytes
    [GateOutput.cpp, MidiInputTask.cpp, PitchCvOutput.cpp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]
2019-10-20 Connected up pitch cv
2019-10-25 Read in sysex messages
    [Configuration.h]
2019-10-26 Added protobuf for configurtion message
    [Configuration.h]
2019-10-27 renamed WrapperMessage to ConfigWrapper
    [Configuration.h]
2019-10-27 Use protobuf object to store config
    [Configuration.h]
2019-10-27 Tidy up serial messasges
    [Configuration.h]
2019-10-27 Use configured scale to determine note pitches
    [Configuration.h]
2019-10-27 Read config message into second buffer to prevent overriting with partial messages
    [Configuration.cpp]
2019-10-29 added note pressure event
2019-10-30 Added pitch bend event
2019-11-03 Implemented pitch bend
2019-11-05 Added trigger output task
    [Configuration.h]
2019-11-07 Fixed compile errors and added convertVelocity function
    [CvOutput.cpp]
2019-11-07 set velocity on note on event
2019-11-14 Define cv config and percussion channel config
    [Configuration.h]
2019-11-15 Increase size of controller mapping field
    [Configuration.h]
2019-11-16 Add function to get cv controller mapping
    [Configuration.h]
2019-11-16 moved cv output service to drivers
2019-11-23 channel pressure and program change don't have a 2nd data byte
2019-11-23 Fixed redeclaration of byte3
    [MidiInputTask.cpp, hwconfig.h]
2019-12-03 Add percussion event to midi processor
    [Configuration.h]
2019-12-03 Implemented note and channel pressure events
2019-12-08 A few fixes to MAX11300 library (bit order wrong, read/write bit backwards, using conditional && instead of bitwise &, not setting select pin to output mode)
    [CvOutput.cpp, PitchCvOutput.cpp, hwconfig.h]
2019-12-13 Wait until next byte before sending control change message in case there is a LSB control change message.
2019-12-29 Allow differnt drum notes to trigger same drum with different control values
    [Configuration.h]
2019-12-29 Select device MAX11300 device based on index.
2020-03-29 Moved hardware files to this project
    [PGTNX05_mainboard.brd, PGTNX05_mainboard.sch, PGTNX07_gate_out.brd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]
2020-03-29 Tidy up scheamtics
    [PGTNX05_mainboard.brd, PGTNX07_gate_out.brd, PGTNX07_gate_out.sch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]
2020-03-29 Added seperate headers for driving leds from outputs
    [PGTNX07_gate_out.brd, PGTNX07_gate_out.sch]
2020-03-29 IO Expander PCB
    [PGTNX06_ioexpander.brd, PGTNX06_ioexpander.sch]
2020-04-18 Added correct diode type BZX55C12
    [PGTNX05_mainboard.brd, PGTNX05_mainboard.sch]
2020-04-18 Add resistor values
    [PGTNX05_mainboard.brd, PGTNX05_mainboard.sch]
2020-04-19 Refactored code to work on Teensy 4.0 with new PCBs.
    [Configuration.h]
2020-05-09 Reset clock counter on start and stop. All notes off on reset message
    [CvOutput.cpp, MidiInputTask.cpp]
2020-05-10 Corrected reset function call
    [MidiInputTask.cpp]
2020-06-04 Moved to platform IO project
    [Configuration.h]
2020-07-02 Correct teensy41 to teensy 40, fixed warning
    [PitchCvOutput.cpp]
2020-07-02 changed cv pin numbers to match hardware
2021-05-24 Fixed note off bug when two midi channels have same note on
    [MidiInputTask.cpp]
2021-05-29 CHnaged pin numner and added some sample of polyphonic config
2021-06-20 Use second clock output for reset trigger
    [Configuration.cpp]
